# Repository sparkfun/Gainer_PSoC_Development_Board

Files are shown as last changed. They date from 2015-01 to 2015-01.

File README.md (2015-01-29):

SparkFun Gainer PSoC Development Board
========================================

SparkFun Gainer PSoC Development Board

[*SparkFun Gainer PSoC Development Board (DEV-08480)*](https://www.sparkfun.com/products/8480)

This board utilizes the Cypress PSoC CY8C29466 IC making it a great board for digital and analog projects where AtoD and DtoA is required.
 Simple USB interface for reprogramming - no external programmer needed.

Repository Contents
-------------------
* **/Hardware** - All Eagle design files (.brd, .sch)

License Information
-------------------
The hardware is released under [Creative Commons ShareAlike 4.0 International](https://creativecommons.org/licenses/by-sa/4.0/).

Gainer is a simple board developed by Shigeru Kobayashi and the team at Gainer.cc. 

Distributed as-is; no warranty is given.

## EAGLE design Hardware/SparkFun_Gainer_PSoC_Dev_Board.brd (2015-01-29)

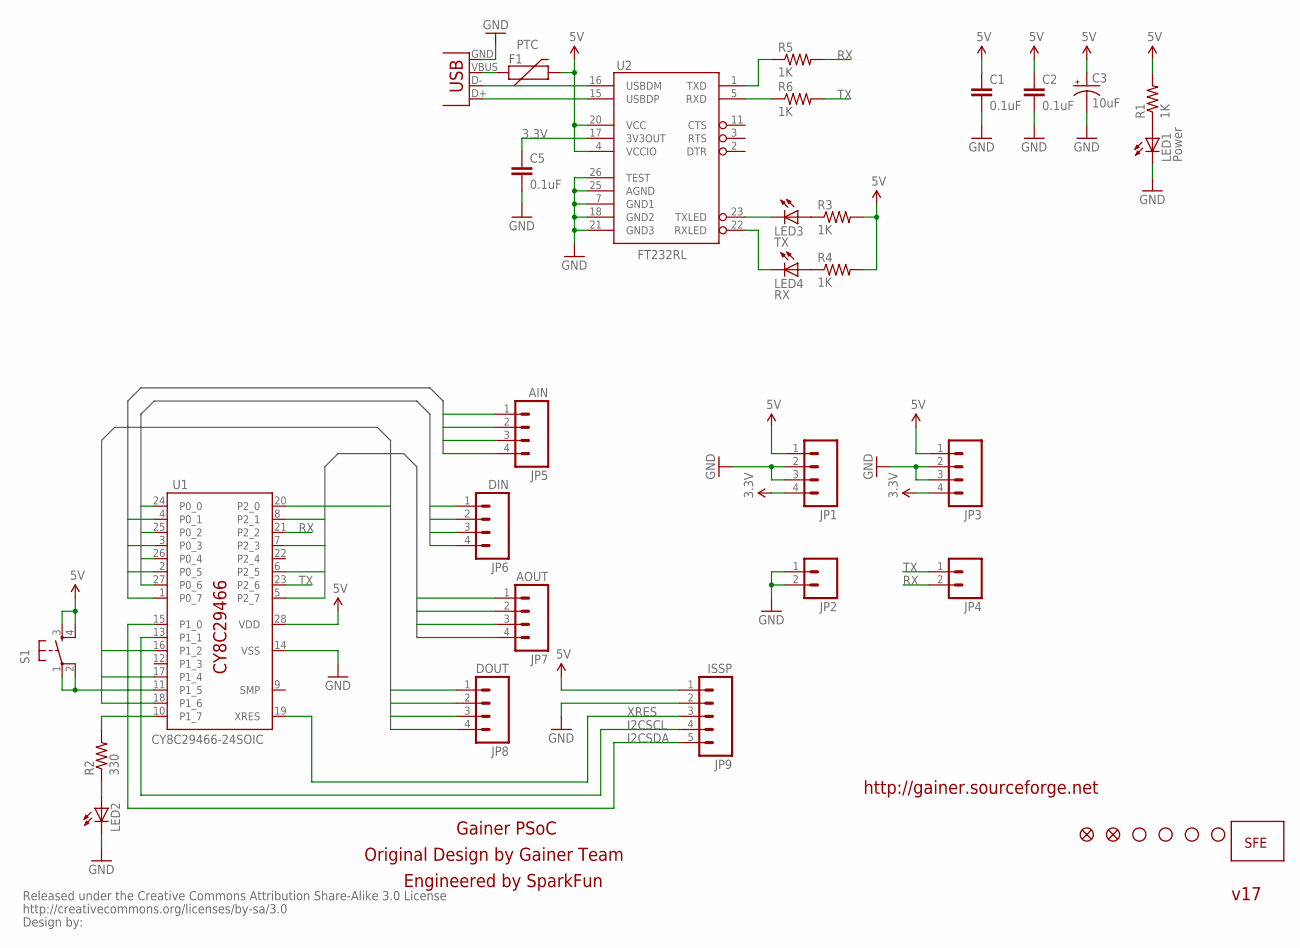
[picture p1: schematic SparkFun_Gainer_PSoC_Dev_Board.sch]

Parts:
C1, C2, C5: 0.1uF; C0402
C3: 10uF; EIA3216
F1: PTC; PTC-1206
JP1, JP3: M04PTH; 1X04
JP2, JP4: M02PTH; 1X02
JP5: AIN; 1X04
JP6: DIN; 1X04
JP7: AOUT; 1X04
JP8: DOUT; 1X04
JP9: ISSP; 1X05
LED1: Power; LED-1206
LED2: LED1206; LED-1206
LED3: TX; LED-0603
LED4: RX; LED-0603
R1, R3, R4, R5, R6: 1K; C0402
R2: 330; C0402
S1: TAC_SWITCHSMD; TACTILE_SWITCH_SMD
U1: CY8C29466-24SOIC; SOIC28
U2: FT232RL; SSOP28DB
U$1: LOGO-SFENEW; SFE-NEW-WEBLOGO
U$10, U$17: FIDUCIAL1X2; FIDUCIAL-1X2
U$12, U$13, U$14, U$15: STAND-OFF
U$18: CREATIVE_COMMONS
X2: USBSMD; USB-MINIB

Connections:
3.3V: C5.1, JP1.4, JP3.4, U2.17 (3V3OUT)
5V: C1.1, C2.1, C3.A (+), F1.2, JP1.1, JP3.1, JP9.1, R1.2, R3.2, R4.2, S1.3, S1.4, U1.28 (VDD), U2.4 (VCCIO), U2.20 (VCC)
AIN1: JP5.1, U1.1 (P0_7)
AIN2: JP5.2, U1.2 (P0_5)
AIN3: JP5.3, U1.3 (P0_3)
AIN4: JP5.4, U1.4 (P0_1)
AOUT1: JP7.1, U1.5 (P2_7)
AOUT2: JP7.2, U1.6 (P2_5)
AOUT3: JP7.3, U1.7 (P2_3)
AOUT4: JP7.4, U1.8 (P2_1)
DIN1: JP6.1, U1.27 (P0_6)
DIN2: JP6.2, U1.26 (P0_4)
DIN3: JP6.3, U1.25 (P0_2)
DIN4: JP6.4, U1.24 (P0_0)
DOUT1: JP8.1, U1.20 (P2_0)
DOUT2: JP8.2, U1.18 (P1_6)
DOUT3: JP8.3, U1.17 (P1_4)
DOUT4: JP8.4, U1.16 (P1_2)
GND: C1.2, C2.2, C3.C (-), C5.2, JP1.2, JP1.3, JP2.1, JP2.2, JP3.2, JP3.3, JP9.2, LED1.C, LED2.C, U1.14 (VSS), U2.7 (GND1), U2.18 (GND2), U2.21 (GND3), U2.25 (AGND), U2.26 (TEST), X2.GND
I2CSCL: JP9.4, U1.13 (P1_1)
I2CSDA: JP9.5, U1.15 (P1_0)
unnamed: LED3.A, R3.1
unnamed: F1.1, X2.VBUS
unnamed: LED1.A, R1.1
unnamed: LED4.A, R4.1
unnamed: R6.1, U2.5 (RXD)
unnamed: LED4.C, U2.22 (RXLED)
unnamed: S1.1, S1.2, U1.11 (P1_5)
unnamed: R2.2, U1.10 (P1_7)
unnamed: LED2.A, R2.1
unnamed: U2.16 (USBDM), X2.D-
unnamed: U2.15 (USBDP), X2.D+
unnamed: R5.1, U2.1 (TXD)
unnamed: LED3.C, U2.23 (TXLED)
RX: JP4.2, R5.2, U1.21 (P2_2)
TX: JP4.1, R6.2, U1.23 (P2_6)
XRES: JP9.3, U1.19 (XRES)

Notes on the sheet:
Gainer PSoC
http://gainer.sourceforge.net
Original Design by Gainer Team
Engineered by SparkFun
v17

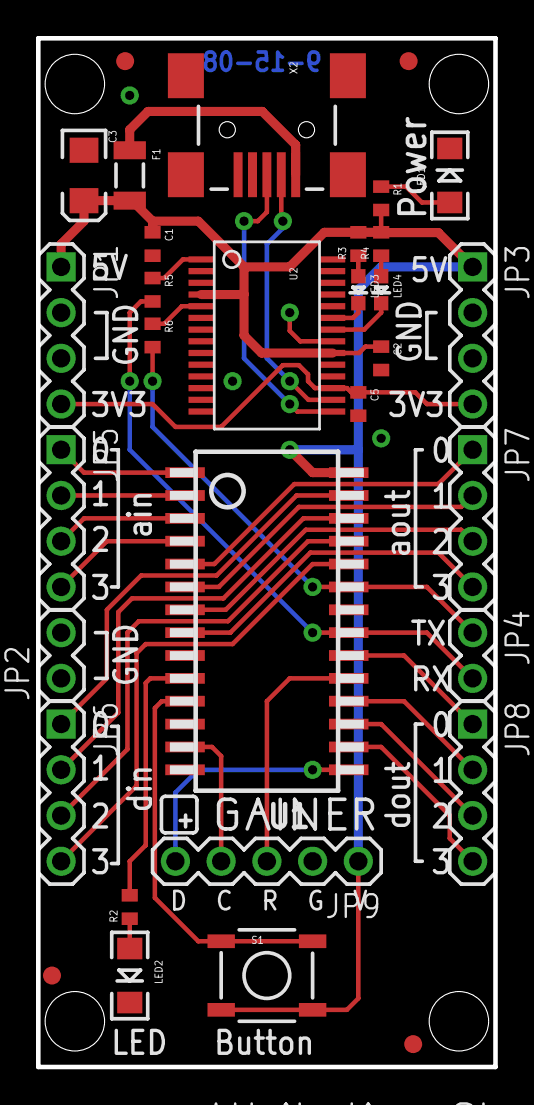
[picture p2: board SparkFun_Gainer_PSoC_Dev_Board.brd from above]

Board: 2 copper layers, 25.4 x 57.1 mm, 39 parts (1 on the bottom side), 37 nets.

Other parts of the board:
E$1, E$2: FIDUCIAL-1X2
U$19: GAINER_LOGO

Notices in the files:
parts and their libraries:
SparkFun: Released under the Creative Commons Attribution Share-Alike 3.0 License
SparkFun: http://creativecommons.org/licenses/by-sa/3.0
